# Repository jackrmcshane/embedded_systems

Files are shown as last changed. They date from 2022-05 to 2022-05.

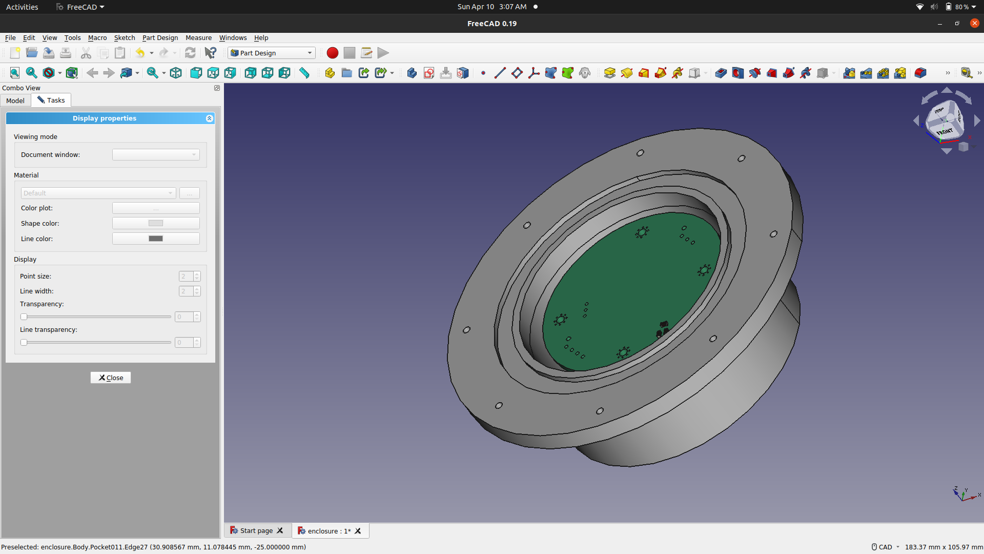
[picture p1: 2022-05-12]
lab9/bottom_enclosure.png

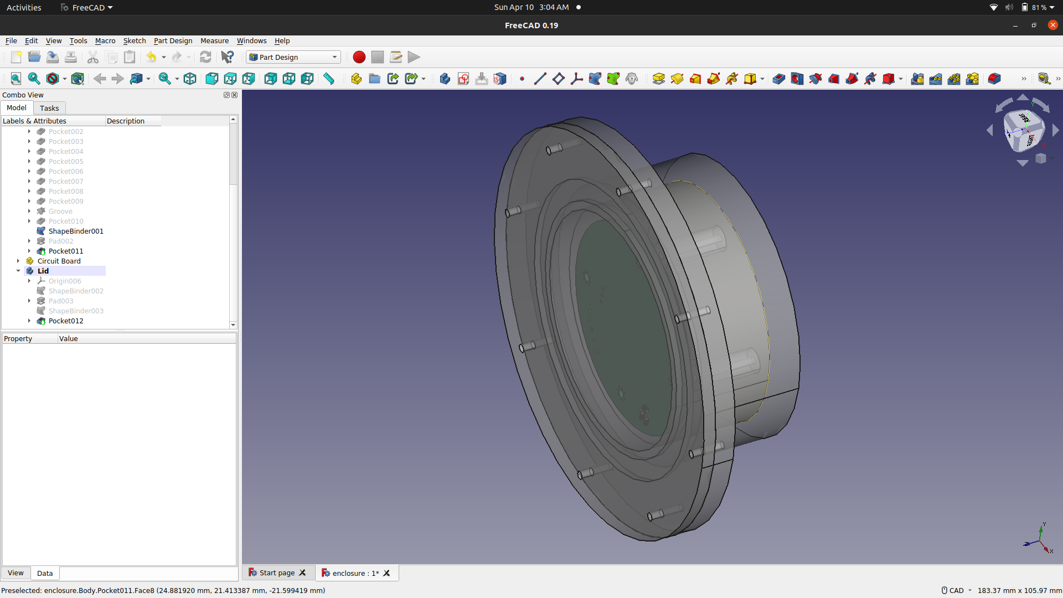
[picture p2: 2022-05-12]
lab9/lid_enclosure.png

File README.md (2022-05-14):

## Light Sensor System for the Hoosier National Forest

> This repository houses the code, circuit schematics, and 3D models for the light sensor system.

> The light sensor system is an autonomous, ultra-low power embedded microcontroller system designed to take light-level readings from the night sky. Over the course of hte next year, it will be deployed in teh Hoosier National Forest to collect sensor readings for the Forest Service in their attempt to gain 'dark sky' status.

> The software utilized by the system is an interrupt driven program that utilized the system's Real-Time Clock (RTC) to generate regular interrupts at fifteen minute intervals. These intervals are generated between the times of 8:00pm and 8:00am, daily, over the course of the system's one year lifetime so that the sensor system is able to capture how low the light levels reach over the course of each night. These readings are then stored bythe software in the system's FLASH memory back for collection at the end of the device's lifetime.

> TGhe electrical system, responsible for powering the system's CPU and peripheral devices, maximizes its operational life cycle by switching between a high powered running mode used for taking readings and low power mode which conserves the state of the machine whilst still limiting the expense of power. Utilizing the modes of operation that we do, the maximum lifetime of the light sensor system has been estimated to be three years using the STMCube software, allowing confidence that the system can operate for a year without issue.

> As part of the overall system, a 3D printable, water-resistant enclosure has been designed to house the electrical components. An enclosure such as the one we designed is a necessary part of the larger system not only because it will shield the PCB and its components from external forces such as dirt and rain while it is out in the forest, but it will also protect wildlife from damaging the electrical system and vice versa. The enclosure has a securable lid for easy access to the PCB and a port on the bottom of the enclosure for access to a 3-pin connector for later collection of the data captured by the light sensor system.

> The system has been designed to be as low cost as possible such that it may be produced en masse for the Forest Service so that they might deploy the devices throughout the 200,000 acres of the forest and maximize their chances to collect the low-light level readings that they need.

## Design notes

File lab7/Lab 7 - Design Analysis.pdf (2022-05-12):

Jack McShane | Rob Hageboeck
E314 Embedded Systems
Lab 7: Design Analysis

## Executive Summary

This design analysis compares 4 different MCUs from a couple of vendors. While all of the microcontrollers reviewed below could be used to tackle this project, we believe the STM32L432KC is best suited to the light sensor project overall. STM’s 432KC ships with all of the hardware desired for the application including ample flash memory for data storage. Other options considered such as the FRDM-K32L2A4S or the raspberry pi pico were either more expensive than the 432KC, had too long a time table for shipping, or required the purchase of additional hardware. Consequently, we are certain that the STM432LKC MCU is currently the best option for the Hoosier National Forest’s light monitoring undertaking.

## Discussion of Alternatives

THE STM32L432KC:

Vendor: This microcontroller unit comes from STMicroelectronics. It is based around the Cortex-M4 processor and comes with a floating point unit.

Cost: The current cost of an STM32L432KC unit is $10.99 and can ship immediately.

Memory Size: The STM32L432KC MCU comes with 64KB of static random-access memory as well as 256KB of single bank flash memory for long term storage.

Peripherals: The STM32L432KC MCU is packaged with a single 12-bit analog to digital converter for reading from our analog peripherals such as the battery and the light sensor. The MCU also ships with 2 12-bit DACs, an op amp for signal amplification, 2 ultra-low-power comparators, 3 USARTs, 1 low-power UART, 2 SPIs, a true random number generator, 3 general purpose timers, 2 low-power timers, and a 77 vector NVIC.

Power Utilization: The STM32L432KC supports four modes of operation: run, standby, stop and shutdown. Run mode operation draws 84μA/Mhz while standby, stop and shutdown draw 280nA, 8nA and 1μA respectively.

Package Size: UFQFPN-32

THE STM32L412KB:

Vendor: This MCU comes from STMicroelectronics. And is equipped with the aforementioned Cortex-M4 and FPU.

Cost: The STM32L412KB costs $10.32 per board and currently has a 16 week lead time.

Memory Size: The STM32L412KB MCU has 128KB of single bank flash memory and 40KB of SRAM.

Peripherals: The device comes with 2 ADCs, 2 op amps, 1 low-power comparator, 3 USARTs, 1 low-power UART for wake-up, a true random number generator, 3 general purpose timers, 2 low-power timers, and an 83 vector NVIC.

Power Utilization: Again, the MCU is capable of operating in the same four distinct modes of operation as above although the power draw in each of these modes is different. This MCU draws power ranging from .7μA to 79μA/Mhz.

Package Size: QFN-32

FRDM-K32L2A4S:

Vendor: The vendor for this MCU is NXP USA. This board is built around the ARM Cortex-M0+ processor.

Cost and Availability: The FRDM-K32L2A4S currently costs $33.92 and has a 34 week lead time.

Memory Size: The K32L2A4S MCU comes with 128KB static RAM and 512KB of flash memory for long term data storage.

Peripherals: The microcontroller comes with low-leakage wakeup unit, 32 vector NVIC, 16-bit ADC, 12-bit DAC, 2 high-speed analog comparators, 2 low-power timers, two periodic interrupt timers, 3 low-power UART modules, and a FlexIO module for emulating UART and SPI.

Power Utilization: The board operates at 3.0V and has four modes of operation: run, wait, very-low-power, and stop. Current draw while operating in each of these modes is 9.6mA, 7.0mA, 483.7μA, and 264.5μA respectively.

Package Size: 100-LQFP

THE RASPBERRY PI PICO RP2040

Vendor: Raspberry Pi, building around the RP2040 ARM chipset which is designed based on the Cortex M0+ microprocessor.

Cost and Availability: Available at $4.00 per development board. Based around the RP2040 chip which does not have widespread commercial use and is not currently being squeezed by manufacturing delays.

Memory Size: The Raspberry Pi Pico comes with 264 KB multi-bank static RAM.

Peripherals: 12-bit ADC, 2x UART, 2x SPI, 2x I2c support, 1 Timer (4x alarms), 1 x Real Time Counter, 16 PWM channels, 8 PIO state machines

Power Utilization: Can be powered with voltages between 1.8V and 5V, supports a low power ‘dormant’ mode and ‘sleep’ mode. Board converts input to 3.3V for the microprocessor to run on.

Package Size: QFN-56

## Recommendation

The raspberry pi pico is the least expensive microcontroller we considered for the project. Its price point is lowest by a factor of 2. While this is a huge selling point for the MCU, the pico does not ship with all the desired hardware for the job. Most notably, there is no on board debugger for the MCU, requiring the purchase of more hardware than just the pico itself.

The STM32L412KB is a great fit for the project, and might just be the ideal board. It has all the desired hardware, including an on-board debugger for troubleshooting code. However, global supply chains are in terrible shape since the recent pandemic and the 412KB will take at least 16 weeks to ship after ordering.

NXP’s FRDM-K32L2A4S is an MCU that has a great amount of functionality. It comes with a low-leakage wakeup unit, an ADC, low-power timers, interrupt timers and more. Nonetheless, this board suffers similarly to the 412KB MCU as it will take more than 30 weeks to ship and comes at a price of $34 per unit.

Finally, our recommendation for the light capture project is the STM32L432KC. It has more than an adequate amount of memory for device’s project lifetime, has all the necessary hardware and functionality, comes with STM’s strong development pipeline, costs $11 per unit, and will be shipped as soon as it is ordered from the vendor.

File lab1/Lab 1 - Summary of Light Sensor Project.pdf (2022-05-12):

E314 Lab 1 Report
Jack McShane & Rob Hageboeck 01-21-2022

Light Sensor Project Design Document

Problem Statement

The Hoosier National Forest is trying to attain Dark Sky status from the International Dark Sky Association. To accomplish this, the forest needs to demonstrate sufficient occasional darkness to qualify and be designated a Dark Sky Forest.

The Forest Service is trying to obtain ‘Dark Sky’ status for the Hoosier National Forest in an effort to improve forest preservation and boost tourism. To obtain this designation, the HNF must provide an adequate number of low light-level readings to the International Dark Sky Association. Our goal is to aid the HNF’s effort through the design and fabrication of an autonomous light sensor which will provide these low light-level readings over the course of a calendar year.

Objectives

Our objective for this project is to design a battery operated, long lasting light sensor to collect data for the Dark Sky Designation. The sensor will optimally be capable of operating for several years to reduce the required human interaction with the device. The device will be designed with fault tolerant software to prevent unwanted shutdowns or data gathering issues. The device will also be designed to survive in a variety of weather conditions and around the local wildlife over its deployment duration. The system design will be reproducible because the Hoosier National Forest (client) will be deploying more than one device to accomplish the Dark Sky Designation goal.

The objective of this project is the development of a low-light sensor that is capable of reporting its captured readings for use in obtaining ‘Dark Sky’ designation. The sensor will be battery operated and must be able to maintain operation for the duration of a full year. The sensor will be posted outside, in the midst of the forest, and must therefore be designed to weather any and all moisture it encounters. The design will also have to be relatively inexpensive as the Forest Service plans to deploy the sensor in the hundreds, and potentially thousands.

Constraints

As with any project, cost is a factor. While singleton embedded systems are often what one would consider cheap, the issue comes with the plethora of devices required to institute the overall infrastructure at proper scale. The Hoosier National Forest covers nine counties in Indiana (over two hundred thousand acres) and gathering light intensity readings throughout the expanse requires thousands of light sensor systems. Minimizing the cost of individual sensors is therefore a crucial step in the design.

As follows from implementing low cost systems, there are a pair of constraints that go hand in hand: the necessary lifetime of the sensor and the battery power available to the system. Due to the previously mentioned budget constraints, battery power is a scarce resource that the overall system must manage carefully. In turn, every aspect of the light sensor design must take into account the power it will consume during its operation. The inherent interplay between cost, power availability and management, and the necessary lifetime will be the defining aspect of the project.

That is not to say that there are no other constraints present in the lifecycle of the light sensor system. The primary concern on the software side of the design is the nonexistent virtual memory. Virtual memory is an invaluable resource for modern multipurpose operating systems that offers much in the way of memory management. This resource will not be available to the light sensor system and most aspects of memory management will have to be done manually by the team. The limited memory available on board will pose many challenges as not only will careful management software have to be written to avoid overwriting memory that is already in use, but overall memory capacity will have to be accounted for when logging the data over time.

This leads to yet another constraint present in the design of the light sensor system: the capacity of the sensor for networking. This aspect of the design is important for two reasons. Firstly, networking capabilities make the data more accessible to those that will be using it. If the sensor can transfer data to devices using some form of networking protocol, eg. Bluetooth, then ease of access to data is vastly improved, making data collection and use more convenient. As well, transferring this data from the device will alleviate some of the potential concerns involving lack of memory.

Finally, there are environmental concerns which constrain the design process. As these sensors will be outdoors, in the forest, where moisture is abundant. As most know, any moisture that reaches the components of a microprocessor will surely damage it. The design therefore, will have to be waterproof such that continued operation, regardless of weather conditions, can be guaranteed. To this end, a waterproof enclosure for the device has been provided and the final design for the light sensor system must fit within it.

While there may be more constraints that become evident later during the design process, these are the ones that will surely dictate the design process throughout.

Available Systems & their Pros and Cons

Light data loggers can be found online for prices starting at $75 and going upward of $500. These systems offer similar data recordings of the proposed embedded system but many have additional features to justify greater costs. Some devices have cellular options as well as solar panel support to improve the duration of deployment on battery life. These systems often feature additional instruments as well, with some equipped with barometers, thermometers, and other weather sensing equipment. The links below demonstrate some of these products which have similar capabilities.

https://microdaq.com/data-loggers/light.phphttps://www.onsetcomp.com/products/data-loggers/light-intensity/

Challenges & Opportunities

Battery life and environmental factors represent the biggest challenges of this design. A single battery must stretch several years to make the device an effective embedded system whereas if battery life was not an issue, many other features could be added (i.e. Bluetooth, Speaker) to improve the Hoosier National Forest’s experience with the product. Environmental issues greatly impact the design since temperature and humidity must be taken into account year round to effectively account for condensation. The end system will have to be unappealing to animals and park visitors to protect against its removal and prevent the data from being lost.

This system represents a unique learning opportunity to build an embedded system from start to finish as well as developing a product for a real client. Additionally, since this light sensor has been implemented in previous semesters and years there is an opportunity to improve upon previous design and implementation errors to create a more efficient and less error-prone embedded system.

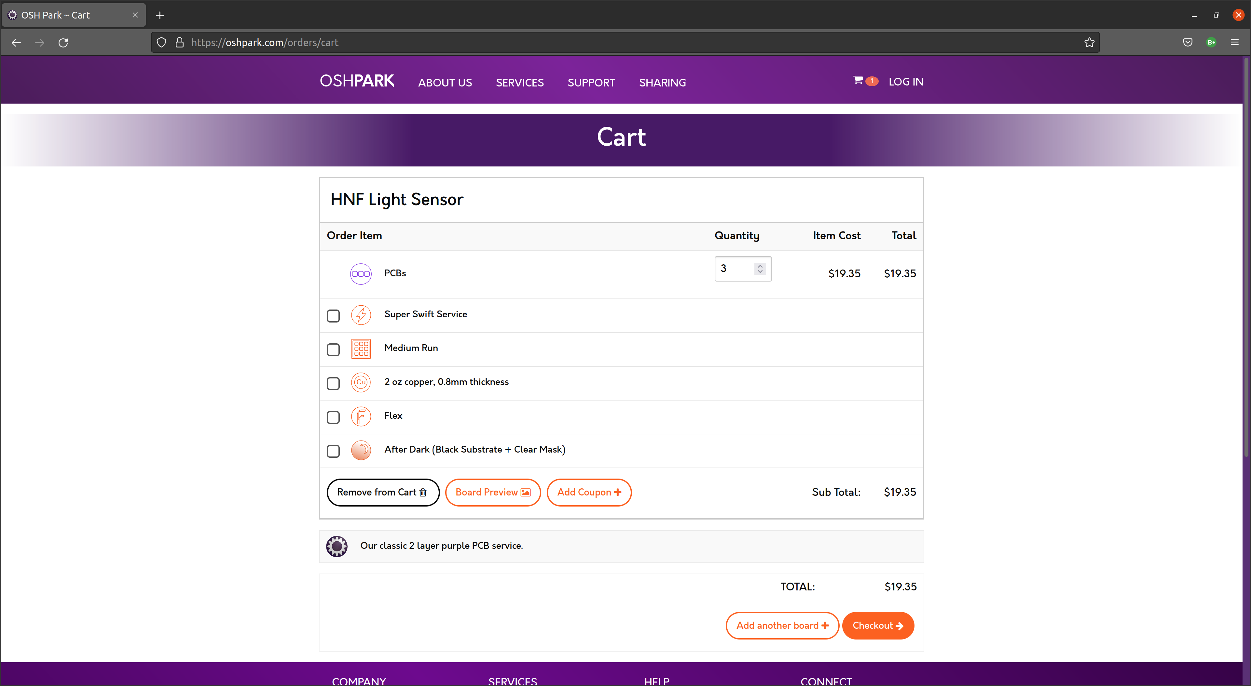
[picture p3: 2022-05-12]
lab8/kicad-oshpark.png

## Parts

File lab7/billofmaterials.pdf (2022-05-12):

Component Manufacturer's Number 1060TR
0603YC105KAT2A
0603YC105KAT2A
CC0603JRX7R7BB104
CC0603JRX7R7BB104
TSL237S-LF
B3B-XH-AM(LF)(SN)
B4B-XH-AM(LF)(SN)
RMCF0603JT200R
RMCF0603JT200R
FTSH-107-01-L-DV-K-TR
TG-3541CE
STM32L432KCU6

Features Built-In to Board Mounting Hole x4
Jumper Open x1
Test Point x3

Component Description | Reference Designator(s)
Battery Holder (Open) Coin, 0.0mm 1 Cell SMD (SMT) Tab | BT1
CAP CER 1UF 16V X7R 0603 | C1
CAP CER 1UF 16V X7R 0603 | C2
CAP CER 0.1UF 16V X7R 0603 | C3
CAP CER 0.1UF 16V X7R 0603 | C4
SENSOR OPT 635NM AMB SIDELOOKER | IC1
CONN HEADER VERT 3POS 2.5MM | J1
CONN HEADER VERT 4POS 2.5MM | J2
RES 200 OHM 5% 1/10W 0603 | R1
RES 200 OHM 5% 1/10W 0603 | R2
Headers & Wire Housings High Reliability Header Strips, 0.050 pitch U1
TCXO Oscillators 32.768 KHz, 30pF | U2
ARM Microcontrollers - MCU Ultra-low-power FPU Arm Cortex-M4 MCU 80 MHz 256 Kbytes of Flash , USB U3

Unit Cost (order of 1000) Extended Cost
$ | 0.8687
$ | 0.0418
$ | 0.0418
$ | 0.0184
$ | 0.0184
$ | 1.8653
$ | 0.0788
$ | 0.1025
$ | 0.0027
$ | 0.0027
$ | 2.8800
$ | 2.9100
$ | 4.7200

Link
https://www.digikey.com/en/products/detail/keystone-electronics/1060TR/4935558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 https://www.digikey.com/en/products/detail/kyocera-avx/0603YC105KAT2A/1888462
https://www.digikey.com/en/products/detail/kyocera-avx/0603YC105KAT2A/1888462
https://www.digikey.com/en/products/detail/yageo/CC0603JRX7R7BB104/5195185
https://www.digikey.com/en/products/detail/yageo/CC0603JRX7R7BB104/5195185
https://www.digikey.com/en/products/detail/ams/TSL237S-LF/3095041https://www.digikey.com/en/products/detail/jst-sales-america-inc/B3B-XH-AM-LF-SN/1651029https://www.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

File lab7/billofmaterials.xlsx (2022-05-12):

Component Manufacturer's Number | Component Description | Reference Designator(s) | Unit Cost (order of 1000) | Extended Cost | Link
1060TR | Battery Holder (Open) Coin, 0.0mm 1 Cell SMD (SMT) Tab | BT1 | $0.8687 |  | https://www.digikey.com/en/products/detail/keystone-electronics/1060TR/4935558
0603YC105KAT2A | CAP CER 1UF 16V X7R 0603 | C1 | $0.0418 |  | https://www.digikey.com/en/products/detail/kyocera-avx/0603YC105KAT2A/1888462
0603YC105KAT2A | CAP CER 1UF 16V X7R 0603 | C2 | $0.0418 |  | https://www.digikey.com/en/products/detail/kyocera-avx/0603YC105KAT2A/1888462
CC0603JRX7R7BB104 | CAP CER 0.1UF 16V X7R 0603 | C3 | $0.0184 |  | https://www.digikey.com/en/products/detail/yageo/CC0603JRX7R7BB104/5195185
CC0603JRX7R7BB104 | CAP CER 0.1UF 16V X7R 0603 | C4 | $0.0184 |  | https://www.digikey.com/en/products/detail/yageo/CC0603JRX7R7BB104/5195185
TSL237S-LF | SENSOR OPT 635NM AMB SIDELOOKER | IC1 | $1.8653 |  | https://www.digikey.com/en/products/detail/ams/TSL237S-LF/3095041
B3B-XH-AM(LF)(SN) | CONN HEADER VERT 3POS 2.5MM | J1 | $0.0788 |  | https://www.digikey.com/en/products/detail/jst-sales-america-inc/B3B-XH-AM-LF-SN/1651029
B4B-XH-AM(LF)(SN) | CONN HEADER VERT 4POS 2.5MM | J2 | $0.1025 |  | https://www.digikey.com/en/products/detail/jst-sales-america-inc/B4B-XH-AM-LF-SN/1651035
RMCF0603JT200R | RES 200 OHM 5% 1/10W 0603 | R1 | $0.0027 |  | https://www.digikey.com/en/products/detail/stackpole-electronics-inc/RMCF0603JT200R/1758007
RMCF0603JT200R | RES 200 OHM 5% 1/10W 0603 | R2 | $0.0027 |  | https://www.digikey.com/en/products/detail/stackpole-electronics-inc/RMCF0603JT200R/1758007
FTSH-107-01-L-DV-K-TR | Headers & Wire Housings High Reliability Header Strips, 0.050 pitch | U1 | $2.8800 |  | https://www.mouser.com/ProductDetail/Samtec/FTSH-107-01-L-DV-K-TR?qs=%252BZP6%2F%252BtExtDlh0wyxE013Q%3D%3D
TG-3541CE | TCXO Oscillators 32.768 KHz, 30pF | U2 | $2.9100 |  | https://www.mouser.com/ProductDetail/Epson-Timing/TG-3541CE-327680KXB3?qs=PzGy0jfpSMvw8fWVlt%2F85g%3D%3D
STM32L432KCU6 | ARM Microcontrollers - MCU Ultra-low-power FPU Arm Cortex-M4 MCU 80 MHz 256 Kbytes of Flash , USB | U3 | $4.7200 |  | https://www.mouser.com/ProductDetail/STMicroelectronics/STM32L432KCU6?qs=dTJS0cRn7oiybcTRwI97Tw%3D%3D
Features Built-In to Board
Mounting Hole x4
Jumper Open x1
Test Point x3

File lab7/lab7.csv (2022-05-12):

Source: | /Users/rob/Git/ES-SPRING-2022/lab7/lab7.kicad_sch
Date: | Saturday, March 12, 2022 at 10:33:48 PM
Tool: | Eeschema (6.0.2-0)
Generator: | /Applications/KiCad/KiCad.app/Contents/SharedSupport/plugins/bom_csv_grouped_by_value.py
Component Count: | 21
Individual Components:
Item | Qty | Reference(s) | Value | LibPart | Footprint | Datasheet | Description | Manufacturer_Name | Manufacturer_Part_Number | Mouser Part Number | Mouser Price/Stock
 |  | BT1 | Battery_Cell | Device:Battery_Cell | Battery:BatteryHolder_Keystone_1060_1x2032 | ~
 |  | C1 | 1uF | Device:C | Capacitor_SMD:C_0603_1608Metric_Pad1.08x0.95mm_HandSolder | ~
 |  | C2 | 0.1uF | Device:C | Capacitor_SMD:C_0603_1608Metric_Pad1.08x0.95mm_HandSolder | ~
 |  | C3 | 1uF | Device:C | Capacitor_SMD:C_0603_1608Metric_Pad1.08x0.95mm_HandSolder | ~
 |  | C4 | 0.1uF | Device:C | Capacitor_SMD:C_0603_1608Metric_Pad1.08x0.95mm_HandSolder | ~
 |  | H1 | MountingHole | Mechanical:MountingHole | MountingHole:MountingHole_2.2mm_M2_Pad_Via | ~
 |  | H2 | MountingHole | Mechanical:MountingHole | MountingHole:MountingHole_2.2mm_M2_Pad_Via | ~
 |  | H3 | MountingHole | Mechanical:MountingHole | MountingHole:MountingHole_2.2mm_M2_Pad_Via | ~
 |  | H4 | MountingHole | Mechanical:MountingHole | MountingHole:MountingHole_2.2mm_M2_Pad_Via | ~
 |  | IC1 | TSL237S-LF | e314-2020:TSL237S-LF | e314-2020:TSL237S-LF | https://componentsearchengine.com/Datasheets/1/TSL237S-LF.pdf | Light To Frequency & Light To Voltage Light to Frequency High Responsivity | ams | TSL237S-LF | 856-TSL237S-LF | https://www.mouser.com/Search/Refine.aspx?Keyword=856-TSL237S-LF
 |  | J1 | Conn_01x03 | Connector_Generic:Conn_01x03 | Connector_JST:JST_XH_B3B-XH-AM_1x03_P2.50mm_Vertical | ~
 |  | J2 | Conn_01x04 | Connector_Generic:Conn_01x04 | Connector_JST:JST_XH_B4B-XH-AM_1x04_P2.50mm_Vertical | ~
 |  | JP1 | Jumper_3_Open | Jumper:Jumper_3_Open | Jumper:SolderJumper-3_P1.3mm_Open_RoundedPad1.0x1.5mm | ~
 |  | R1 | R_US | Device:R_US | Resistor_SMD:R_0603_1608Metric_Pad0.98x0.95mm_HandSolder | ~
 |  | R2 | R_US | Device:R_US | Resistor_SMD:R_0603_1608Metric_Pad0.98x0.95mm_HandSolder | ~
 |  | TP1 | TestPoint | Connector:TestPoint | TestPoint:TestPoint_Pad_D1.5mm | ~
 |  | TP2 | TestPoint | Connector:TestPoint | TestPoint:TestPoint_Pad_D1.5mm | ~
 |  | TP3 | TestPoint | Connector:TestPoint | TestPoint:TestPoint_Pad_D1.5mm | ~
 |  | U1 | STDC14 | e314-2020:STDC14 | e314-2020:ftsh_14p_connector
 |  | U2 | TG-3541CE | e314-2020:TG-3541CE | e314-2020:TG-3541CE
 |  | U3 | STM32L432KCUx | MCU_ST_STM32L4:STM32L432KCUx | Package_DFN_QFN:QFN-32-1EP_5x5mm_P0.5mm_EP3.45x3.45mm | http://www.st.com/st-web-ui/static/active/en/resource/technical/document/datasheet/DM00257205.pdf
Collated Components:
Item | Qty | Reference(s) | Value | LibPart | Footprint | Datasheet | Description | Manufacturer_Name | Manufacturer_Part_Number | Mouser Part Number | Mouser Price/Stock
1 | 1 | BT1 | Battery_Cell | Device:Battery_Cell | Battery:BatteryHolder_Keystone_1060_1x2032 | ~
2 | 2 | C1, C3 | 1uF | Device:C | Capacitor_SMD:C_0603_1608Metric_Pad1.08x0.95mm_HandSolder | ~
3 | 2 | C2, C4 | 0.1uF | Device:C | Capacitor_SMD:C_0603_1608Metric_Pad1.08x0.95mm_HandSolder | ~
4 | 4 | H1, H2, H3, H4 | MountingHole | Mechanical:MountingHole | MountingHole:MountingHole_2.2mm_M2_Pad_Via | ~
5 | 1 | IC1 | TSL237S-LF | e314-2020:TSL237S-LF | e314-2020:TSL237S-LF | https://componentsearchengine.com/Datasheets/1/TSL237S-LF.pdf | Light To Frequency & Light To Voltage Light to Frequency High Responsivity | ams | TSL237S-LF | 856-TSL237S-LF | https://www.mouser.com/Search/Refine.aspx?Keyword=856-TSL237S-LF
6 | 1 | J1 | Conn_01x03 | Connector_Generic:Conn_01x03 | Connector_JST:JST_XH_B3B-XH-AM_1x03_P2.50mm_Vertical | ~
7 | 1 | J2 | Conn_01x04 | Connector_Generic:Conn_01x04 | Connector_JST:JST_XH_B4B-XH-AM_1x04_P2.50mm_Vertical | ~
8 | 1 | JP1 | Jumper_3_Open | Jumper:Jumper_3_Open | Jumper:SolderJumper-3_P1.3mm_Open_RoundedPad1.0x1.5mm | ~
9 | 2 | R1, R2 | R_US | Device:R_US | Resistor_SMD:R_0603_1608Metric_Pad0.98x0.95mm_HandSolder | ~
10 | 3 | TP1, TP2, TP3 | TestPoint | Connector:TestPoint | TestPoint:TestPoint_Pad_D1.5mm | ~
11 | 1 | U1 | STDC14 | e314-2020:STDC14 | e314-2020:ftsh_14p_connector
12 | 1 | U2 | TG-3541CE | e314-2020:TG-3541CE | e314-2020:TG-3541CE
13 | 1 | U3 | STM32L432KCUx | MCU_ST_STM32L4:STM32L432KCUx | Package_DFN_QFN:QFN-32-1EP_5x5mm_P0.5mm_EP3.45x3.45mm | http://www.st.com/st-web-ui/static/active/en/resource/technical/document/datasheet/DM00257205.pdf

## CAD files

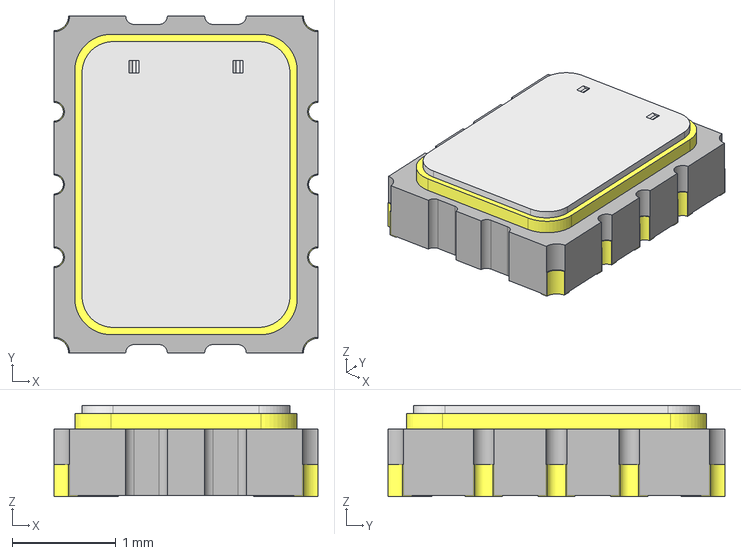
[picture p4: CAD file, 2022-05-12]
kicad/parts/3D_Models/03__3DMODEL__TG-3541CE_REV0_ASM_sp.step
2.54 x 3.24 x 0.88 mm

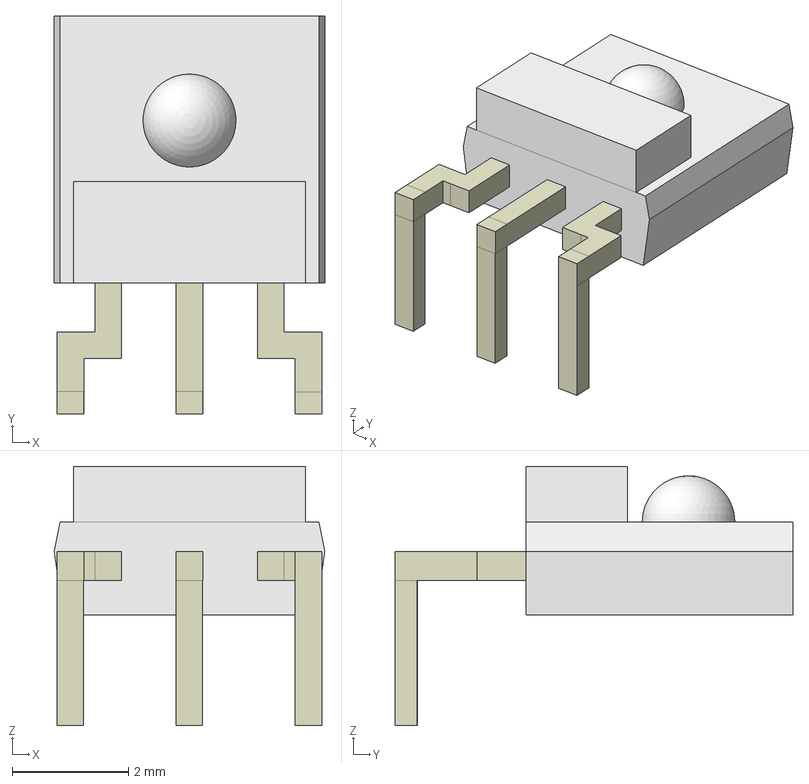
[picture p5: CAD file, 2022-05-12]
kicad/parts/3D_Models/Fusion_sp.step
4.66 x 6.85 x 4.46 mm

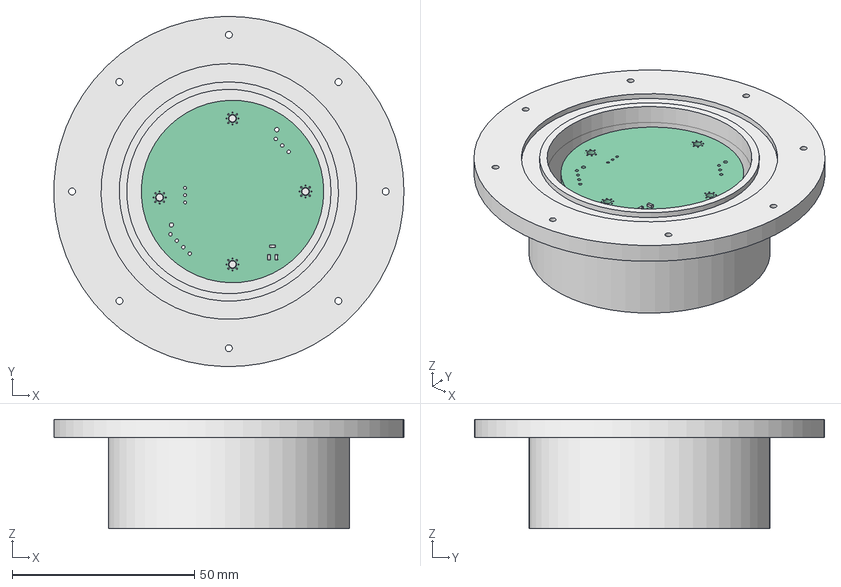
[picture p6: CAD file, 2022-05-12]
lab9/enclosure1.FCStd
95.9 x 96.0 x 30.0 mm
Pcb_9147
R2_R_0603_1608Metric_18504254b625 x 2
C1_C_0603_1608Metric_25f668334653 x 4
U3_QFN-32-1EP_5x5mm_Pitch0.5mm_34379c8f1efa
BT1_Keystone_1060_1x2032_c739e21a0837

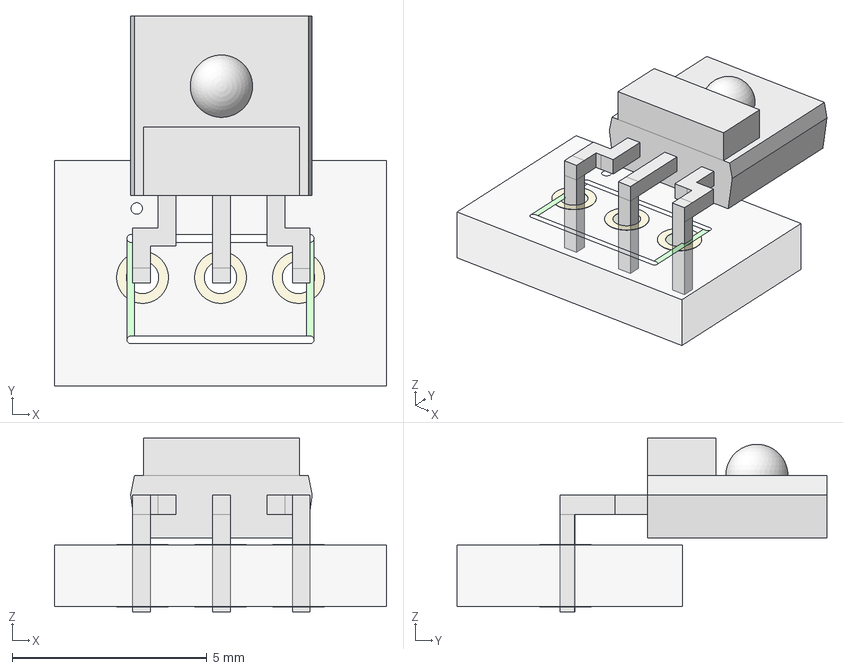
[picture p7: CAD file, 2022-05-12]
kicad/parts/3D_Models/TSL237.FCStd
8.53 x 9.49 x 4.46 mm
FFab
FrontSilk
TopPads
BotPads
PTHs
Pcb
Fusion_sp

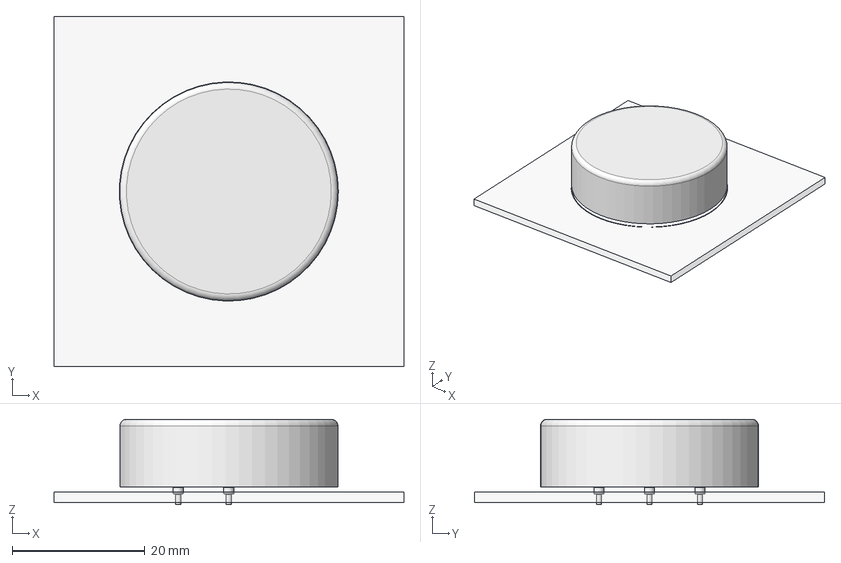
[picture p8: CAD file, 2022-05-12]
kicad/parts/3D_Models/TLH-5935.FCStd
52.8 x 52.8 x 12.9 mm
FrontSilk
TopPads
BotPads
PTHs
Pcb
Body_sp

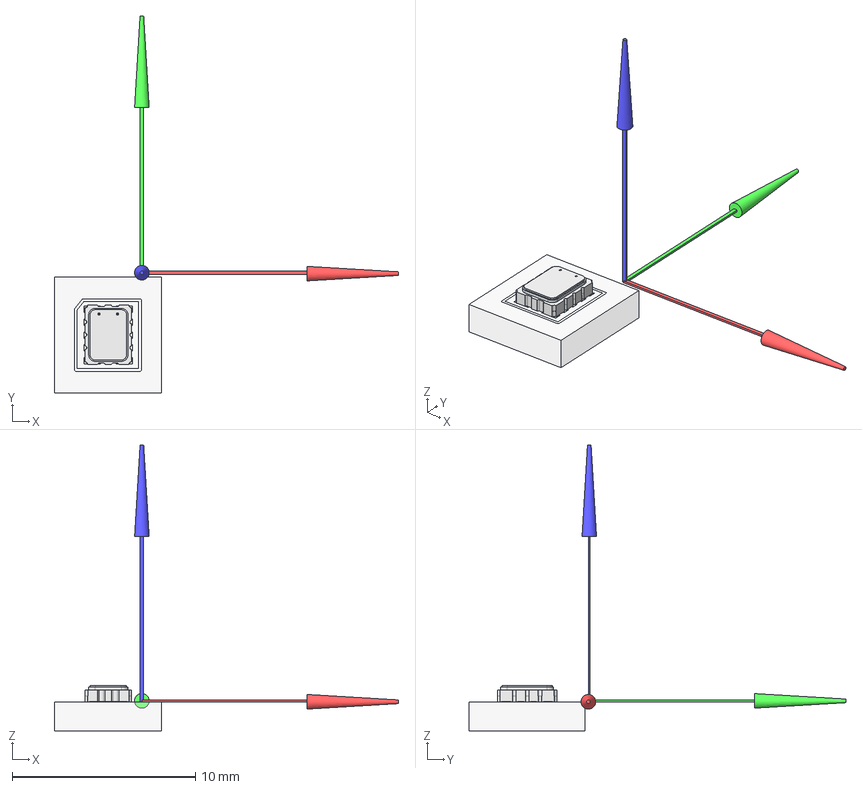
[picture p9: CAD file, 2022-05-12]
kicad/parts/3D_Models/TG-3541CE.FCStd
18.8 x 20.6 x 15.6 mm
FrontSilk
TopPads
Pcb
Z
Y
X
03__3DMODEL__TG-3541CE_REV0_ASM_sp

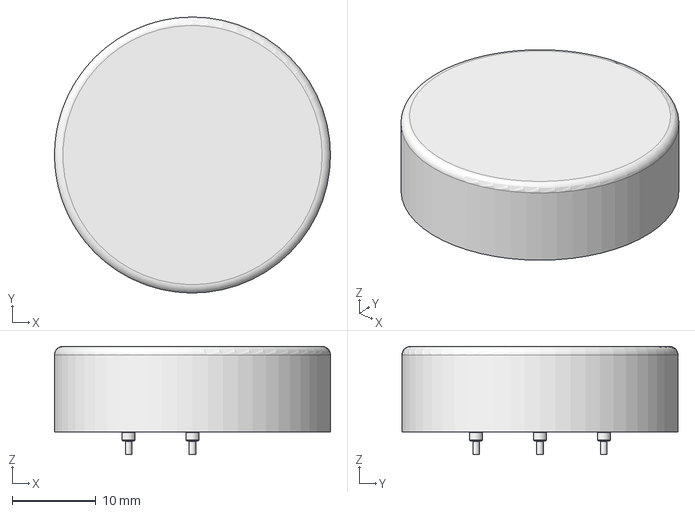
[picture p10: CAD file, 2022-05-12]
kicad/parts/3D_Models/Body_sp.step
32.9 x 32.9 x 12.9 mm

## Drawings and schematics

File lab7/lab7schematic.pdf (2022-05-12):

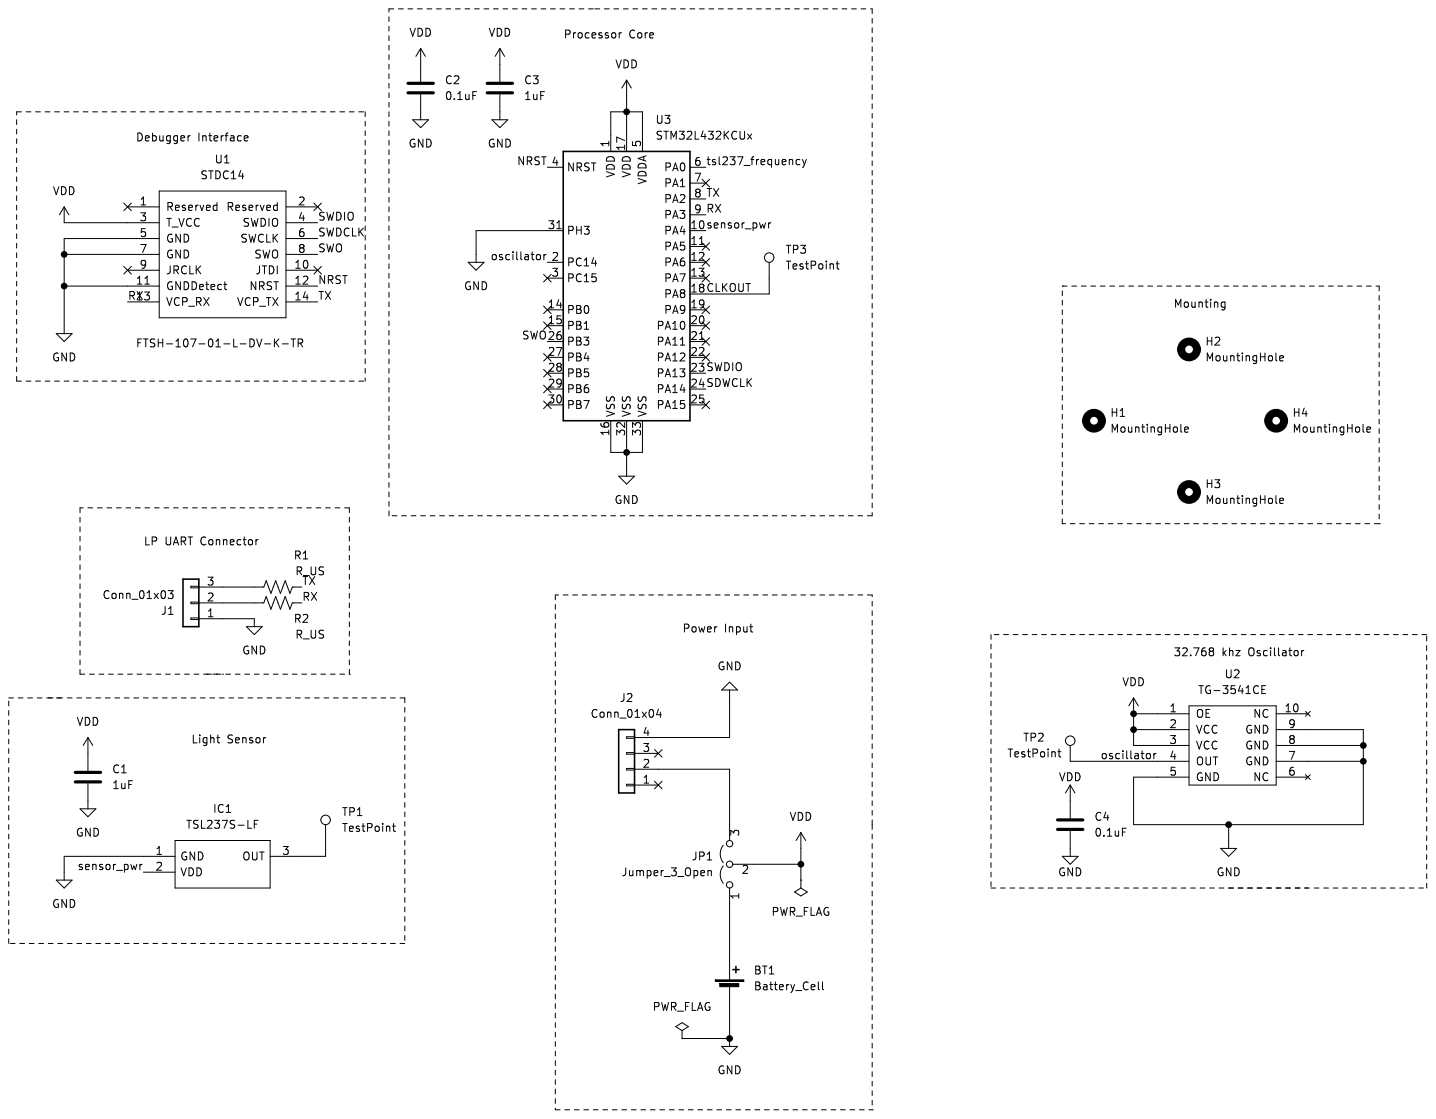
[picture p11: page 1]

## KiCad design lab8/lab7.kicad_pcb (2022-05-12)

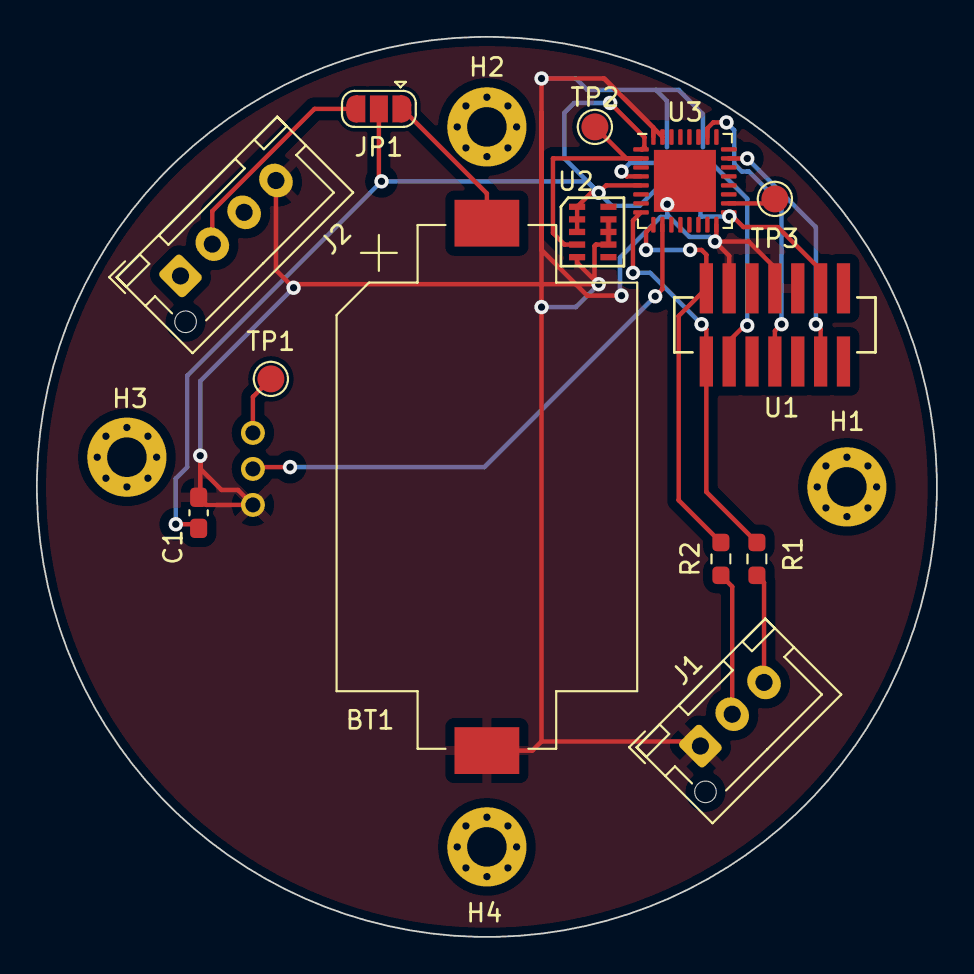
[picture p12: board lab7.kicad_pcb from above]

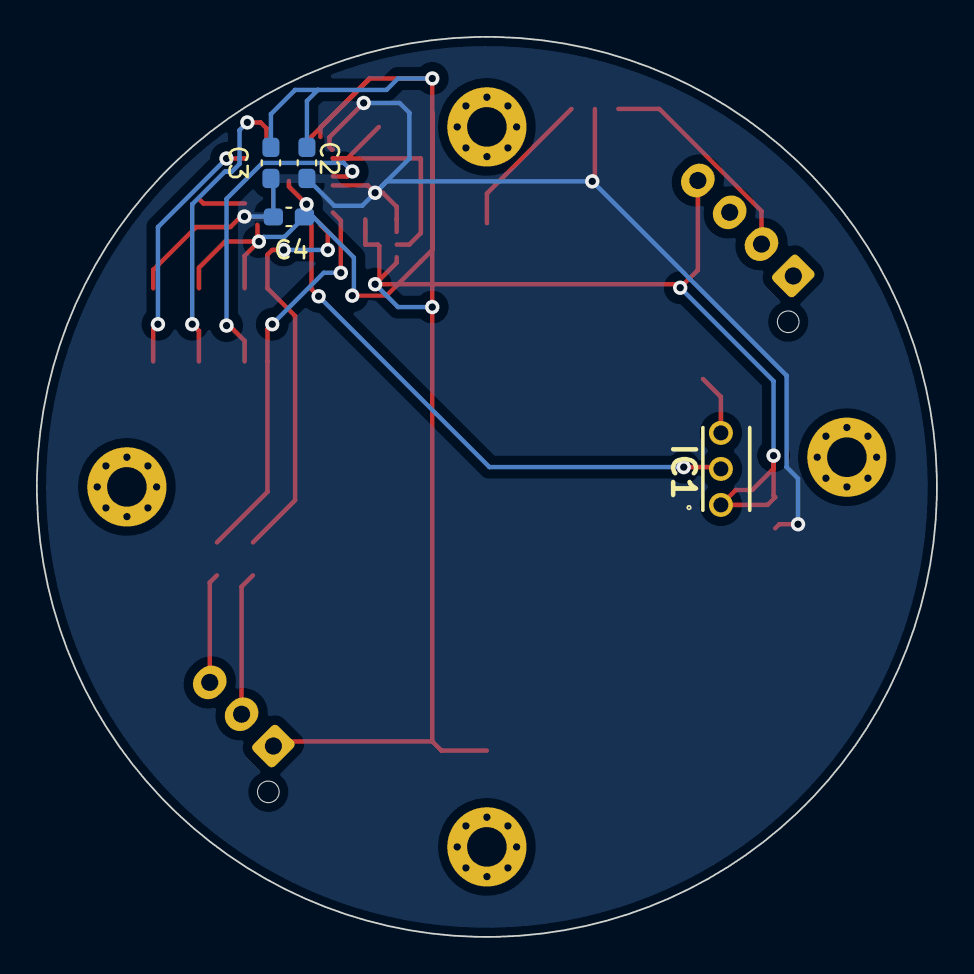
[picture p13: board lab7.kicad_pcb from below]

Board: 2 copper layers, 50.0 x 50.0 mm, 21 parts (4 on the bottom side), 15 nets.

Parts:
BT1: Battery_Cell; BatteryHolder_Keystone_1060_1x2032
C1, C3: 1uF; C_0603_1608Metric_Pad1.08x0.95mm_HandSolder
C2, C4: 0.1uF; C_0603_1608Metric_Pad1.08x0.95mm_HandSolder
H1, H2, H3, H4: MountingHole; MountingHole_2.2mm_M2_Pad_Via
IC1: TSL237S-LF
J1: Conn_01x03; JST_XH_B3B-XH-AM_1x03_P2.50mm_Vertical
J2: Conn_01x04; JST_XH_B4B-XH-AM_1x04_P2.50mm_Vertical
JP1: Jumper_3_Open; SolderJumper-3_P1.3mm_Open_RoundedPad1.0x1.5mm
R1, R2: R_US; R_0603_1608Metric_Pad0.98x0.95mm_HandSolder
TP1, TP2, TP3: TestPoint; TestPoint_Pad_D1.5mm
U1: STDC14; ftsh_14p_connector
U2: TG-3541CE
U3: STM32L432KCUx; QFN-32-1EP_5x5mm_P0.5mm_EP3.45x3.45mm

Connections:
/CLKOUT: TP3.1, U3.18 (PA8)
/NRST: U1.12 (NRST), U3.4 (NRST)
/RX: R2.2, U1.13 (VCP_RX), U3.9 (PA3)
/SWDIO: U1.4 (SWDIO), U3.23 (PA13)
/SWO: U1.8 (SWO), U3.26 (PB3)
/TX: R1.2, U1.14 (VCP_TX), U3.8 (PA2)
/oscillator: TP2.1, U2.4 (OUT), U3.2 (PC14)
/sensor_pwr: IC1.2 (VDD), U3.10 (PA4)
GND: BT1.2 (-), C1.2, C2.2, C3.2, C4.2, IC1.1 (GND), J1.1, J2.4, U1.5 (GND), U1.7 (GND), U1.11 (GNDDetect), U2.5 (GND), U2.7 (GND), U2.8 (GND), U2.9 (GND), U3.16 (VSS), U3.31 (PH3), U3.32 (VSS), U3.33 (VSS)
unnamed: BT1.1 (+), JP1.1 (A)
unnamed: IC1.3 (OUT), TP1.1
unnamed: J1.2, R2.1
unnamed: J1.3, R1.1
unnamed: J2.2, JP1.3 (B)
VDD: C1.1, C2.1, C3.1, C4.1, JP1.2 (C), U1.3 (T_VCC), U2.1 (OE), U2.2 (VCC), U2.3 (VCC), U3.1 (VDD), U3.5 (VDDA), U3.17 (VDD)

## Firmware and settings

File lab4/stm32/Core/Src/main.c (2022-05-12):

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
/* Includes ------------------------------------------------------------------*/
#include "main.h"

/* USER CODE BEGIN Includes */

#include "retarget/retarget.c"

/* USER CODE END Includes */

/* USER CODE BEGIN PD */
#define BUFFER_LENGTH RING_BUFFER_LENGTH

/* USER CODE END PD */

RTC_HandleTypeDef hrtc;

UART_HandleTypeDef huart2;

/* USER CODE BEGIN PV */
RingBuffer ring; 
uint8_t alarm_flag = 0;

/* USER CODE END PV */

void SystemClock_Config(void);
static void MX_GPIO_Init(void);
static void MX_USART2_UART_Init(void);
static void MX_RTC_Init(void);
/* USER CODE BEGIN 0 */

void HAL_RTC_AlarmAEventCallback(RTC_HandleTypeDef *hrtc) {
  alarm_flag = 1;
}

/* USER CODE END 0 */

/**
  * @brief  The application entry point.
  * @retval int
  */
int main(void)
{
  /* USER CODE BEGIN 1 */
  uint8_t ch;
  RingBuffer_Init(&ring); // init ringbuffer
  uint8_t buffer[BUFFER_LENGTH];
  uint8_t *buff = buffer;
  /* USER CODE END 1 */

  /* MCU Configuration--------------------------------------------------------*/

  /* Reset of all peripherals, Initializes the Flash interface and the Systick. */
  HAL_Init();

  /* Configure the system clock */
  SystemClock_Config();

  /* Initialize all configured peripherals */
  MX_GPIO_Init();
  MX_USART2_UART_Init();
  MX_RTC_Init();
  /* USER CODE BEGIN 2 */
  HAL_UART_MspInit(&huart2); // enable NVIC interrupts for USART2
  RetargetInit(&huart2); // redirect IO to the screen
  printf("\r\nSystem Up and Running\n\r");
  prompt();
  /* USER CODE END 2 */

  /* Infinite loop */
  /* USER CODE BEGIN WHILE */
  while (1)
  {
    if(RingBuffer_GetDataLength(&ring) != 0){ // buffer has data
      // read from buffer
      RingBuffer_Read(&ring, &ch, 1);
      if (ch == '\r') {
        printf("\n\r");
        (*buff) = '\0';
        // printf("%s\n\r",buffer);
        execute_command(buffer);
        buff = buffer;
        prompt();
      } else {
        putchar(ch); // print input character to screen
        *(buff) = ch;
        buff++;
      }
    }
    if (alarm_flag) {
      alarm_flag = 0;
      lon();
      HAL_Delay(100);
      lof();
    }
    /* USER CODE END WHILE */

    /* USER CODE BEGIN 3 */
  }
  /* USER CODE END 3 */
}

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


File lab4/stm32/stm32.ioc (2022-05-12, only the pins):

Mcu.UserName=STM32L412KBUx
PA0-CK_IN.Signal=RCC_CK_IN
PA2.GPIO_Label=VCP_TX
PA2.Signal=USART2_TX

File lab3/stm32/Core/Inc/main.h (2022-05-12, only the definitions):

#define VCP_TX_Pin GPIO_PIN_2
#define VCP_TX_GPIO_Port GPIOA
#define SWDIO_Pin GPIO_PIN_13
#define SWDIO_GPIO_Port GPIOA
#define SWCLK_Pin GPIO_PIN_14
#define SWCLK_GPIO_Port GPIOA
#define VCP_RX_Pin GPIO_PIN_15
#define VCP_RX_GPIO_Port GPIOA
#define LD3_Pin GPIO_PIN_3
#define LD3_GPIO_Port GPIOB

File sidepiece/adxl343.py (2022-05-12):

#!/usr/bin/env python3

import spidev
import time
import numpy as np

class adxl343:
    ''' Enables communication between the raspberry pi and the ADXL343 board from Sparkfun '''
    def __init__(self,spi_device=0, ce_pin=0, speed=1000000):
        """
        spi_device: there are two spi ports. It is most common to use port 0. 
        ce_pin: there are two CE pins that are automatically controlled by the pi. 
        speed: the speed for the spi clock is specified here. used to limit spi speed. 
        """
        self.spi = spidev.SpiDev()
        self.spi.open(spi_device, ce_pin)
        self.spi.max_speed_hz = speed   # Sets the maximum speed of the SPI link 
        self.spi.mode = 0b11            # Sets the spi clock phase and polarity to mode 3
        time.sleep(0.5)
        if self.get_device_id() == '0xe5':
            self.enable()
            print("found ADXL343")
        else:
            print("Device ID Incorrect")

    def read_register(self, address):
        address = address | 0x80                     # Set the read mode 
        read_bytes = self.spi.xfer2([address,0x00])  # Send the register address and a dummy byte to clock back data
        return (read_bytes[1])

    def write_register(self, address, data):
        self.spi.xfer2([address,data])
        return(0)
            
    def enable(self):
        """ Set the measure bit in the POWER_CTL Register to enable sensor """
        self.write_register(0x2D, 0x08)
    
    def get_device_id(self):
        """ Read the DEVID register to get back the value of the register"""
        """ Function should return a string that is the output of running the hex function on returned byte"""
        DEVID = self.read_register(0x00)
        return hex(DEVID)

    def convert(self, msb, lsb):
        """Convert the most-significant bits and least significant bits to a single value."""
        # shift and convert msb+lsb to a numpy int16
        numpyint = np.int16(((msb<<8)+lsb))
        # multiply result by 4 (+/-2 g) and divide by 2**10
        return numpyint*4/(2**10)

    def read_x_axis(self):
        """ Read the two bytes for the axis, return a floating point g value on a +/-2g scale. """
        lsb = self.read_register(0x32)
        msb = self.read_register(0x33)
        return self.convert(msb,lsb)
        
    def read_y_axis(self):
        """ Read the two bytes for the axis, return a floating point g value on a +/-2g scale. """
        lsb = self.read_register(0x34)
        msb = self.read_register(0x35)
        return self.convert(msb,lsb)

    def read_z_axis(self):
        """ Read the two bytes for the axis, return a floating point g value on a +/-2g scale. """
        lsb = self.read_register(0x36)
        msb = self.read_register(0x37)
        return self.convert(msb,lsb)
    
if  __name__ == "__main__":
    sensor = adxl343()
    while 1:
        print(sensor.read_x_axis(), sensor.read_y_axis(), sensor.read_z_axis())

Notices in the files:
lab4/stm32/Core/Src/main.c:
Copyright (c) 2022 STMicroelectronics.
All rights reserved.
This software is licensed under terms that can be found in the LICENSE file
